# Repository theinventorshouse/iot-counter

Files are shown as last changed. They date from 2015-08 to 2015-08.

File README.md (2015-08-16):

# iot-counter

Proyecto desarrollado para probar las capcidades del modulo ESP8266 conectado a webSocket para contar con un sistema conectado a internet 24/7.
El contador manda la información en tiempo real a un servidor en internet el cual amacena e informa en tiempo real al cliente web.

**Video demo:** [youtu.be/WBVFUqo8ZCo](https://youtu.be/WBVFUqo8ZCo)

**Demo Web:** [dbug.mx:8000](http://dbug.mx:8000/)

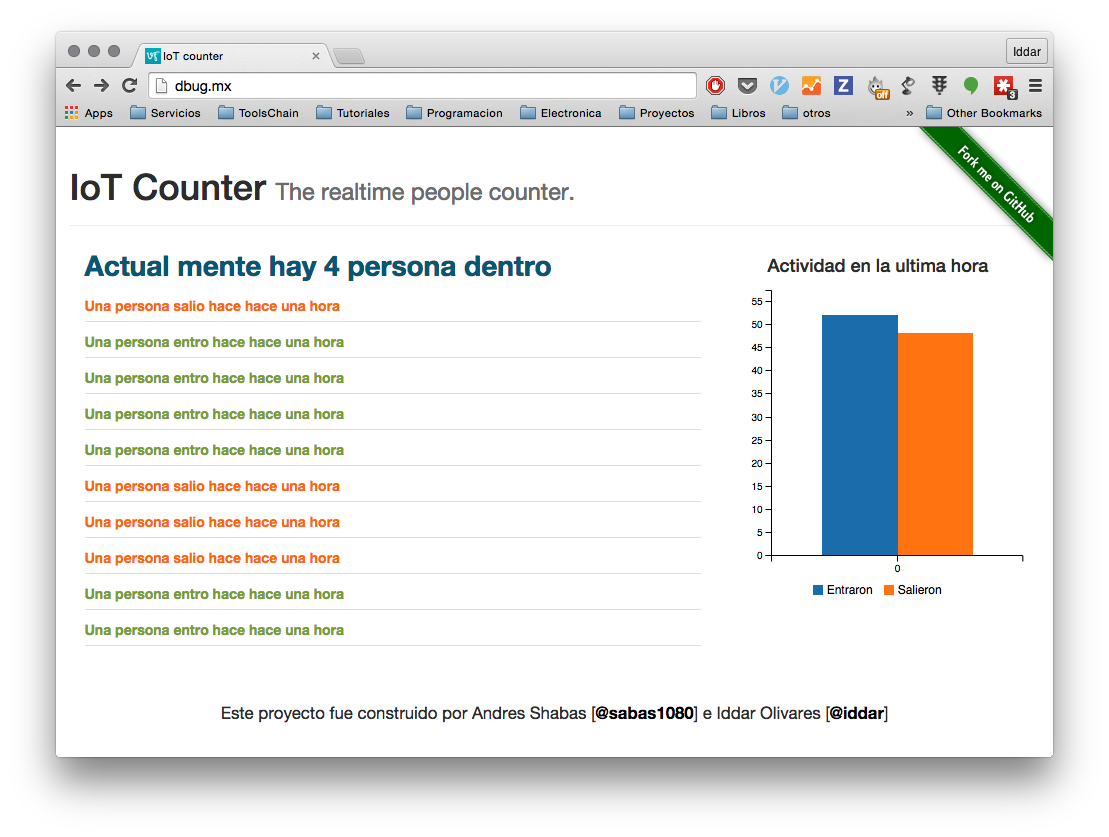
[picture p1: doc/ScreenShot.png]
Web site ScreenShot


El sistema cunte con tres parter principales las cuales:

- Hardware: Conformado por el modulo ESP8266 y los sensores
- Servidor Web: Escrito en Node.js utilizando varias dependencias descritas en el archivo [package.json](https://github.com/theinventorshouse/iot-counter/blob/master/server-socket/package.json) en el direcotrio **server-socket**
- Cliente Web

## Instalación

```sh
$ git clone https://github.com/theinventorshouse/iot-counter.git
$ cd iot-counter
```

### Levantar Servidor local

```sh
$ cd server-socket
$ npm install
$ npm start
```

### Carga de firmware

Para cargar el firmware debes de abrir el proyecto **hardware-counter** que se encuentre en la carpeta del mismo nombre en tu Arduino IDE (con el plugin de ESP instalado)
**Importante:** Recuerda incluir los datos necesarios para hacer las pruebes en tu red (SSID, Password, IPServer)

### Configuracion por defecto

	Hardware Socket: PORT 3000
	Website: PORT 8000

## Costo
Costo de construcción aprox. (Precios en dolares):

- Modulo ESP8266 V.12 $9.95
- PCB $1.00
- 2x Sensor dr Ir + Ir Led $2.20

Costo de mantenimiento del servidor:
El servidor corre en una instancia micro de [digitalocean.com](https://www.digitalocean.com/?refcode=e43f79fbc45c) la cual soporta aporx 4000 Sockets.

- Digitalocean Micro $5.00 Dolares por mes.

## Autores:

- Andres Sabas [@sabas1080](https://github.com/sabas1080)
- Iddar Olivares [@iddar](https://github.com/iddar)

*Creado: Julio 2015*

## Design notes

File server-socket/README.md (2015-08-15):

#IoT Counter

Hardware Socket: PORT 3000
Website: PORT 8000

Test in Node.js v0.12.4

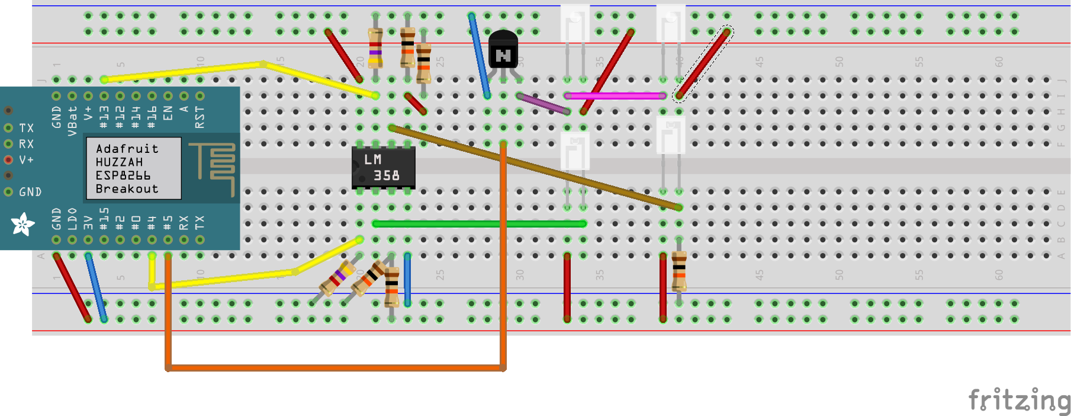
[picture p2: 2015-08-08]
doc/schematic.png

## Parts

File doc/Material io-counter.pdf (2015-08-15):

Andres Sabas | @sabasacustico
Iddar Olivares | @iddar
Fecha | 1/8/2015

## MATERIAL PARA IO-COUNTER

Material | Cantidad
Modulo Wifi ESP8266 Version 12 | 1
LM358 | 1
Fototransistor | 2
Led infrarrojo | 6
Resistencia 10K | 6
Resistencia 4.7K | 2
Fuente de 5v | 1

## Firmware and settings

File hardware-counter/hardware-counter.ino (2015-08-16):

/*
 * Autores:
 * Andres Sabas <s@theinventorhouse.org>
 * Iddar Olivares <iddar@dbug.mx>
 * Creado: Julio 2015
 * Contador de personas con
 * ESP8266 Version 12
 */

#include <Arduino.h>
#include <ESP8266WiFi.h>
#include <WebSocketsClient.h>
#include <Hash.h>

#define SSID "Wifi Name"
#define PASSWORD "Wifi password"
#define SERVER_PORT 3000
#define SERVER_IP "104.236.241.103"
#define USE_SERIAL Serial

WebSocketsClient webSocket;
int StatusFlag = 0;

void webSocketEvent(WStype_t type, uint8_t * payload, size_t lenght) {
  switch(type) {
    case WStype_DISCONNECTED:
      USE_SERIAL.printf("[WSc] Disconnected!\n");
      break;
    case WStype_CONNECTED:
      USE_SERIAL.print("[WSc] Connected to url:dbug.mx ");
      break;
  }

}

void setup() {
  pinMode(4,INPUT);
  pinMode(13,INPUT);
  pinMode(5,OUTPUT);

  attachInterrupt(13, inPeople, RISING);
  attachInterrupt(4, outPeople, RISING);
  digitalWrite(5,HIGH);

  //Informacion de Depuración
  USE_SERIAL.begin(115200);
  USE_SERIAL.setDebugOutput(true);

  USE_SERIAL.println();
  USE_SERIAL.println();

  for(uint8_t t = 4; t > 0; t--) {
    USE_SERIAL.printf("[SETUP] BOOT WAIT %d...\n", t);
    USE_SERIAL.flush();
    delay(1000);
  }

  WiFi.begin(SSID, PASSWORD);
  while (WiFi.status() != WL_CONNECTED) {
    delay(100);
  }

  //Conexion al servidor
  webSocket.begin(SERVER_IP, SERVER_PORT);
  webSocket.onEvent(webSocketEvent);
}

void loop() {
  webSocket.loop();
  //Activacion de interrupciones
  attachInterrupt(13, inPeople, RISING);
  attachInterrupt(4, outPeople, RISING);

  // Envio de datos a servidor
  if(StatusFlag == 1) {
    webSocket.sendTXT("in", 2);
    StatusFlag = 0;
    USE_SERIAL.println("in");
  }

  if(StatusFlag == 2) {
    webSocket.sendTXT("out", 3);
    StatusFlag = 0;
    USE_SERIAL.println("out");
  }

  delay(1500);
}

void inPeople() {
  while(digitalRead(13))
   {
    detachInterrupt(4);
   }

   StatusFlag = 1;
}

void outPeople() {
  while(digitalRead(4))
   {
     detachInterrupt(13);
   }

    StatusFlag = 2;
}

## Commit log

2015-08-06 Primer commit
    Parte del codigo del conteo de personas
2015-08-08 Entrada y salida
    Incluidas interrupciones para entrada y salida en una sola puerta
2015-08-08 Cambiada logica de entrada y salida
2015-08-08 Esquematico e imagen
    Esquematico en fritzing, detalles para mejorar
    [Esquematico.fzz]
2015-08-12 new playload
    [schematic.fzz]
2015-08-12 Cambio Esquematico
    [schematic.fzz]
2015-08-14 Corrección de reinicio
    Ya no se reinicia, modificacion de datos de contacto y datos de wifi
2015-08-15 Correción de datos
2015-08-15 Lista de Material y conexion con el server funcionando
2015-08-15 Variable de estado
    Agregado comentarios de ayuda y variable de estado
2015-08-16 Agrego descripción del proyecto y mejoro la documentación
